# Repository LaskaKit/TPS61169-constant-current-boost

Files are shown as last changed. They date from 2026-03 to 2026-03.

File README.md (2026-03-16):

# LaskaKit TPS61169 Constant Current Boost LED Driver

A compact DC-DC converter designed for powering [high-power LEDs](https://www.laskakit.cz/vyhledavani/?string=LED) or [LED filaments](https://www.laskakit.cz/vyhledavani/?string=LED%20vl%C3%A1kno) from a low-voltage source. The module uses the **TPS61169** integrated circuit, which boosts the input voltage while **maintaining a constant current through the LED**.  

The load connected to the output must require a **higher voltage than the input voltage** for proper current regulation.

Unlike typical boost converters, this device **regulates current instead of output voltage**. The output voltage automatically increases (above the input voltage) to ensure that the LED draws the set current.

Typical applications:

- powering high-power LEDs  
- LED filaments  
- driving multiple LEDs in series from a Li-ion / 5 V source  
- panel backlighting  

The integrated converter can reach efficiencies of up to **90 %**, depending on input voltage and load.

---

# Key Features

- constant current boost LED driver  
- input voltage **2.7 – 5.5 V**  
- output voltage up to **≈38 V**  
- adjustable LED current up to **≈400 mA** using a **DIP switch**  
- open-LED protection  
- soft-start and thermal protection  
- switching frequency approx. **1.2 MHz**

---

# Electrical Limits (Very Important)

These values represent the limits of the chip. Always keep a safety margin when designing your application.

## Input Voltage

**2.7 V – 5.5 V**

Typical sources:

- Li-ion cell  
- 3×AA batteries  
- (USB) 5 V  

---

## Output Voltage

- automatically regulated, the load must require a higher voltage than the input
- maximum approximately **38 V**

The voltage is not fixed – the converter increases it only as much as needed for the LED current to reach the configured value.

---

## Output Current

Typical range:

**25 – 400 mA**

The LED current is set using a resistor connected to the FB pin.  
For easy current adjustment, this module uses a **DIP switch**.

---

## Maximum Power

The real output power is limited by:

- switch current (~1.2 A)  
- efficiency  
- input voltage  

Typical **approximate** values:

| Vin | ILED | Vout max (approx.) |
|----|----|----|
| 5 V | 100 mA | ~30 V |
| 5 V | 200 mA | ~20 V |
| 5 V | 400 mA | ~10 V |

⚠ **Maximum current and maximum voltage cannot be reached simultaneously.**

---

# Connection

Typical usage:

- Connect an LED filament or a series LED string to the output  
- Set the required current using the DIP switch  
- Connect a suitable power source to the input (3×AA batteries, Li-ion battery, or DC adapter)  
- Adjust the brightness of the LED filament using the DIP switch (current can be changed even while the LED is on)  

If you disconnect the LED filament while the input voltage is present, the **over-voltage protection may activate**. After reconnecting the LED filament, it will likely be necessary to **disconnect and reconnect the input power (restart the driver)**.

---

# Important Notes

## 1. This is NOT a voltage source

This module **is not a standard boost converter**.

Without an LED connected, the output voltage may rise until the **over-voltage protection** is triggered.

Use this driver only with LEDs or other loads designed for **constant current operation**.

---

## 2. Do not exceed the power limits

A common mistake:

400 mA × 30 V = 12 W

This driver **cannot deliver that much power**.

With higher voltage differences, the current must be reduced. See the table of typical values above.

---

## 3. Do not disconnect the output while the input is powered

As mentioned above, disconnecting the load while the input power is present may trigger the chip's **over-voltage protection**. This can shut down the driver.

If you reconnect the LED filament and it does not turn on, the chip must be **restarted** by disconnecting and reconnecting the input power while the load is connected.

---

# Buy the module

https://www.laskakit.cz/laskakit-tps61169-boost-led-driver-s-konstantnim-proudem/

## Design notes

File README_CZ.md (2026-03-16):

# LaskaKit TPS61169 Boost LED driver s konstantním proudem

Kompaktní DC-DC měnič určený pro napájení [výkonových LED](https://www.laskakit.cz/vyhledavani/?string=LED) z nízkého napětí nebo [LED vláken](https://www.laskakit.cz/vyhledavani/?string=LED%20vl%C3%A1kno). Modul využívá integrovaný obvod **TPS61169**, který zvyšuje vstupní napětí a zároveň **udržuje konstantní proud protékající LED**. Zátěž na výstupu musí být na vyšší napětí než je vstupní napětí, aby regulace proudu fungovala správně.

Na rozdíl od běžných boost měničů **nereguluje výstupní napětí, ale proud**. Napětí na výstupu se automaticky přizpůsobí (zvyší než je na vstupu) tak, aby LED odebíraly nastavený proud.

Typické použití:

- napájení výkonových LED
- LED vlákna
- série více LED z Li-ion / 5 V zdroje
- podsvícení panelů

Integrovaný měnič může dosahovat účinnosti až **90 %** v závislosti na vstupním napětí a zatížení.

---

# Klíčové vlastnosti

- boost LED driver s konstantním proudem  
- vstupní napětí **2.7 – 5.5 V**  
- výstupní napětí až **≈38 V**  
- nastavitelný LED proud až **≈400 mA** pomocí DIP přepínače 
- ochrana proti přerušení LED (open-LED protection)  
- soft-start a tepelná ochrana  
- spínací frekvence cca **1.2 MHz**

---

# Elektrické limity (velmi důležité)

Tyto hodnoty jsou limity čipu – při návrhu aplikace je nutné počítat s rezervou.

## Vstupní napětí

**2.7 V – 5.5 V**

Typické zdroje:

- Li-ion článek
- 3×AA
- (USB) 5 V

---

## Výstupní napětí

- automaticky řízené, pro správnou funkčnost musí být zátěž na vyšší napětí
- maximálně cca **38 V**

Napětí není pevné – měnič ho zvýší jen tak vysoko, aby LED teklo nastavený proud.

---

## Výstupní proud

Typicky:

**25 – 400 mA**

Proud je nastaven rezistorem na pinu FB. Pro jednoduchou změnu protékajícího proudu jsme použili DIP přepínač.

---

## Maximální výkon

Reálný výkon je omezen:

- proudem spínače (~1.2 A)
- účinností
- vstupním napětím

Typické **orientační** hodnoty:

| Vin | ILED | Vout max (přibližně) |
|----|----|----|
| 5 V | 100 mA | ~30 V |
| 5 V | 200 mA | ~20 V |
| 5 V | 400 mA | ~10 V |

⚠ **Maximální proud a maximální napětí nelze dosáhnout současně.**

---

# Zapojení

Typické zapojení:

- Na výstup připoj například LED vlákno
- Nastav DIP přepínačem potřebný proud
- Na vstup připoj vhodný zdroj energie - 3xAA baterie, Li-Ion akumulátor, DC adaptér
- Uprav svítivost LED vlákna DIP přepínačem tak, aby vyhovoval tvé potřebě (proud můžeš měnit během svícení)
- Pokud odpojíš LED vlákno z měniče, ale na vstupu je napětí, může se aktivovat ochrana proti přepětí. Po opětovném připojení LED vlákna bude (nejspíše) potřebné odpojit a znovu připojit vstupní napětí (restart)

---

# Na co si dát pozor

## 1. Není to zdroj napětí

Tento modul **není klasický boost měnič**.

Bez LED může výstupní napětí vystoupat až do aktivace přepěťové ochrany na výstupu

Používej jej pouze s LED nebo jinou zátěží určenou pro **konstantní proud**.

## 2. Nepřekračuj výkon

Velmi častá chyba:

400 mA × 30 V = 12 W

To už tento driver **nezvládne**.

Při vyšším rozdílu napětí musí být proud menší. Viz. Typické orientační hodnoty

## 3. Neodpojuj výstup při připojeném vstupu

Jak jsme zmínili výše, při odpojení výstupu a připojeném vstupu se může aktivovat přepěťová ochrana čipu. To může způsobit vypnutí čipu. Pokud opětovně připojíš LED vlákno, může se stát, že LED vlákno nebude svítit. Je potřeba "restartovat" čip a to provedeš odpojením a připojením vstupního napětí při připojené zátěži

---

# Modul koupíš na https://www.laskakit.cz/laskakit-tps61169-boost-led-driver-s-konstantnim-proudem/

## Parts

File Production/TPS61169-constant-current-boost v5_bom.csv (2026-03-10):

Comment | Designator | Footprint | LCSC Part #
0.1uF | C5 | C0402
1R | R3 | R0402 | C25147
1uF/50V | C2 C3 | C0805
2.1R | R4 | R0402
4.2R | R5 | R0402 | C270601
6.8uH/2A | L1 | L5.4X5.2
8.2R | R1 R6 | R0402
10k | R2 | R0402
22uF/10V | C1 | C1206
DSHP04TS-S | S1 | DSHP04TSS
JST-PH-2_SMD/90SMD | P1 | S2B-PH-SM4 | C968533
PMEG4010ER | D1 | SOD123-F
TPS61169DCKR | PS1 | SOT65P210X110-5N
TERMINAL_2_54_2P | T1 T2 | TERMINAL_2_54_2P | C474920

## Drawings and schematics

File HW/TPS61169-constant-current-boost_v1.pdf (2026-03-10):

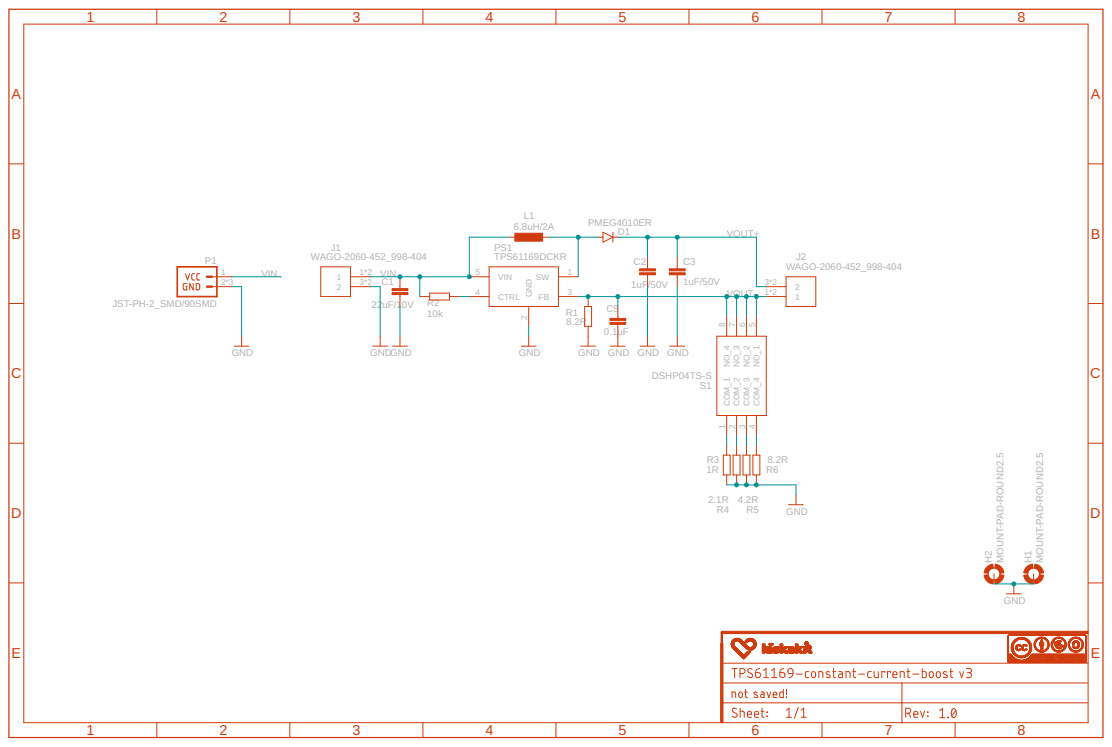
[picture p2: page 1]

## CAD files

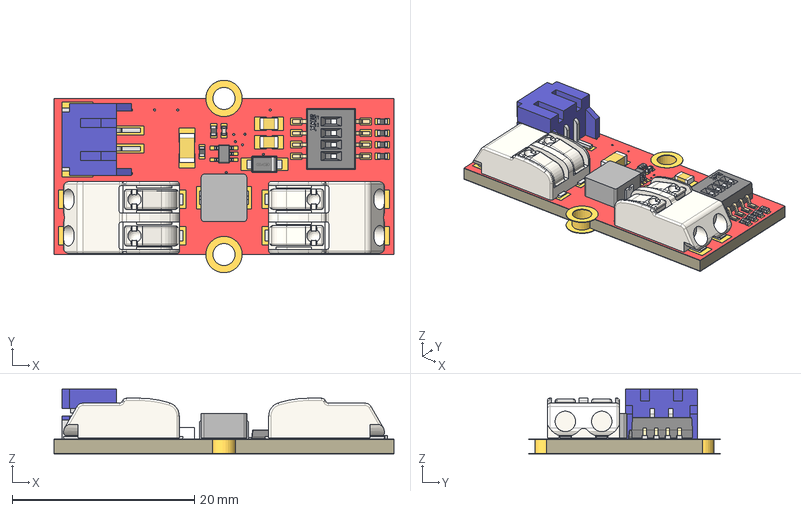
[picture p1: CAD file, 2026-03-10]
3D/TPS61169-constant-current-boost.step
37.3 x 21.1 x 7.12 mm
Board
1-copper
16-copper
1-soldermask
16-soldermask
Pin1
Pin2
CeramicBody
L5.4X5.2
LASKAKIT_HEART_3MM
S2B-PH-SM4
SOD123-F
2,5-PAD x 2
BODY-SOT
LEAD-SOT x 5
LASKKIT_20MM_SILKSCREEN
C0805 x 2
C1206
R0402 x 6

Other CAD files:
3D/TPS61169-constant-current-boost.f3d
